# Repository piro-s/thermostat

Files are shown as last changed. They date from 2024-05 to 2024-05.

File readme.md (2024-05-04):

# Thermostat:  
A board for connecting an inductive load (the width of the tracks allows you  
to connect up to 5A); if large currents are required, then a connector is  
provided for connecting control signals of an external relay (Relay Control).  
Scheme was made using the [article](https://habr.com/ru/companies/unwds/articles/390601/).  

### Schemes:  
###### thermostat_v0.1:  
[pdf](docs/thermostat_v0.1.pdf)  

### Images:  
###### thermostat_v0.1:  
top:  
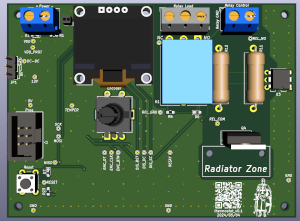
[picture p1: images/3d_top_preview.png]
thermostat_v0.1_top
  
bottom:  
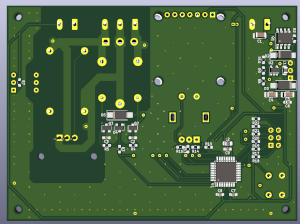
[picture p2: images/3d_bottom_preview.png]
thermostat_v0.1_bottom
  
assembly:  
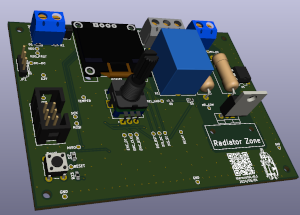
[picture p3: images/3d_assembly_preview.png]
thermostat_v0.1_ass
  

###### gerber:  
Archive for production:  
[thermostat_v0.1](https://github.com/piro-s/thermostat/raw/main/gerber/thermostat_v0.1.zip)

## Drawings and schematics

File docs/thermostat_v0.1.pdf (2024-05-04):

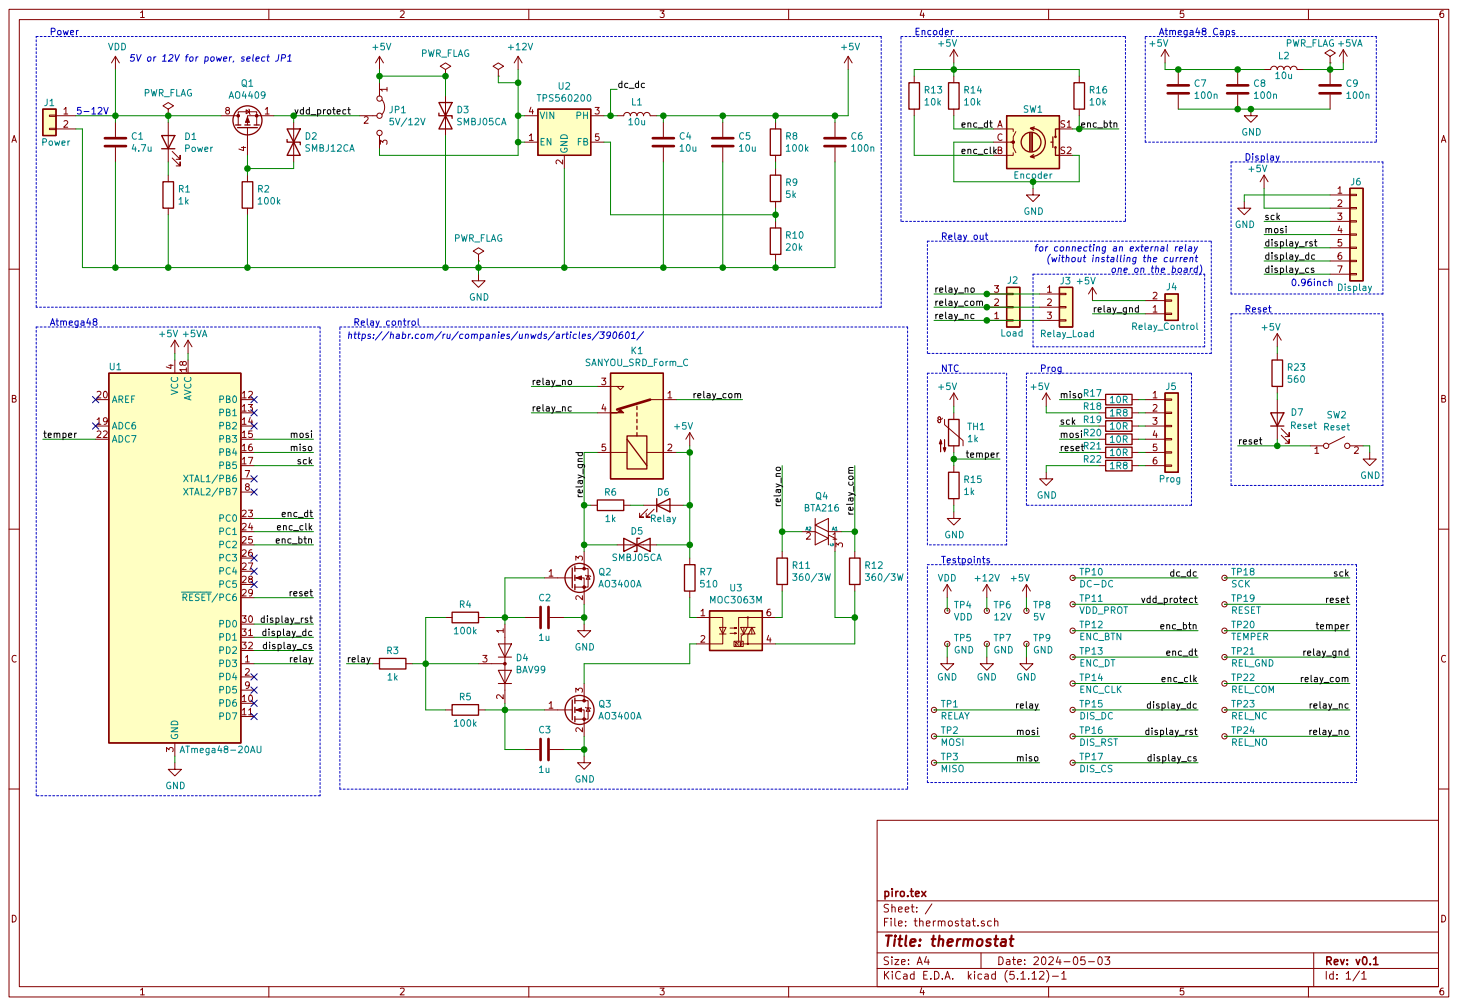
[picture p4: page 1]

5V or 12V for power, select JP1

for connecting an external relay
(without installing the current

one on the board)

Id: 1/1 Title: thermostat File: thermostat.sch Sheet: / piro.tex

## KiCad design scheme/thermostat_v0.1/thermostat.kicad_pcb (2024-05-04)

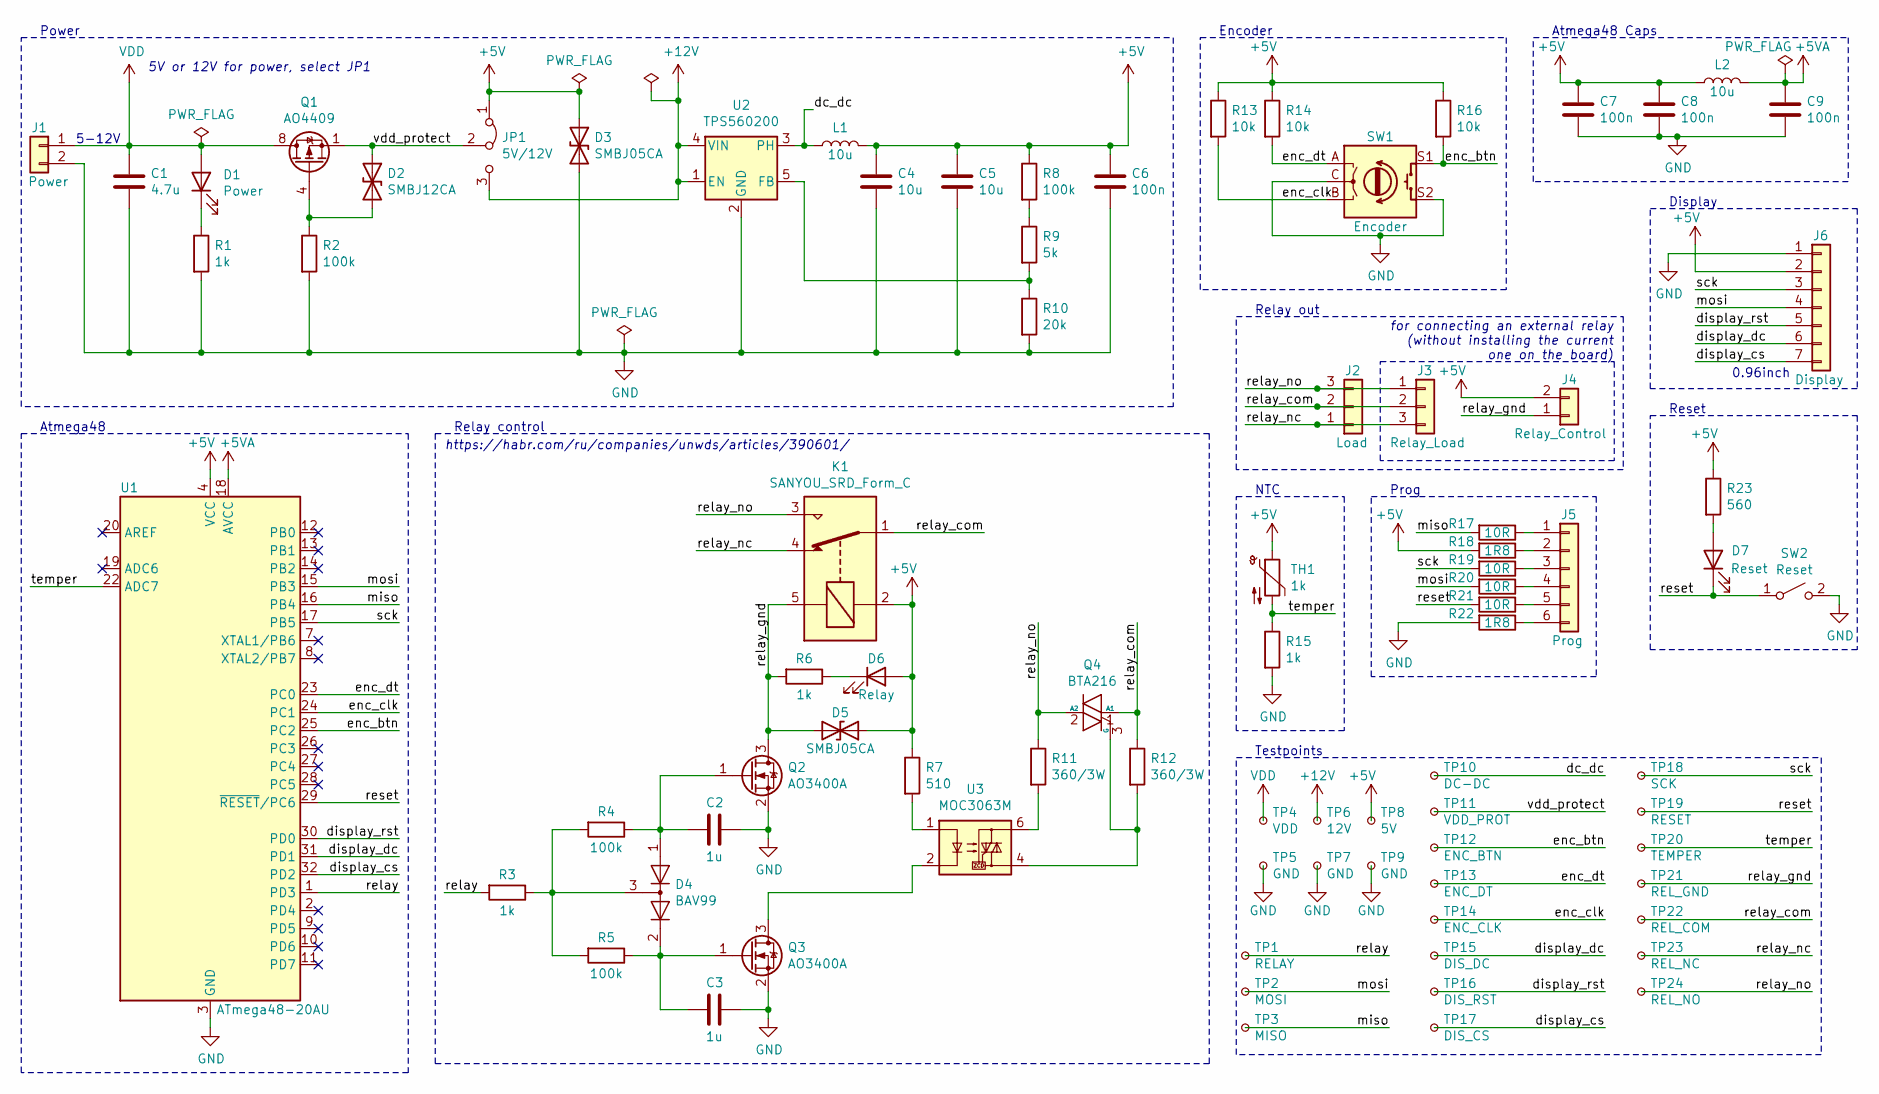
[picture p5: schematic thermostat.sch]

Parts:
C1: 4.7u; C_1206_3216Metric_Pad1.33x1.80mm_HandSolder
C2, C3: 1u; C_0603_1608Metric_Pad1.08x0.95mm_HandSolder
C4, C5: 10u; C_1206_3216Metric_Pad1.33x1.80mm_HandSolder
C6, C7, C8, C9: 100n; C_0603_1608Metric_Pad1.08x0.95mm_HandSolder
D1: Power; D_0603_1608Metric_Pad1.05x0.95mm_HandSolder
D2: SMBJ12CA; D_SMA_Handsoldering
D3, D5: SMBJ05CA; D_SMA_Handsoldering
D4: BAV99; SOT-23
D6: Relay; D_0603_1608Metric_Pad1.05x0.95mm_HandSolder
D7: Reset; D_0603_1608Metric_Pad1.05x0.95mm_HandSolder
J1: Power; PhoenixContact_MCV_1,5_2-G-5.08_1x02_P5.08mm_Vertical
J2: Load; PhoenixContact_MCV_1,5_3-G-5.08_1x03_P5.08mm_Vertical
J3: Relay_Load; SolderWire-0.75sqmm_1x03_P4.8mm_D1.25mm_OD2.3mm
J4: Relay_Control; PhoenixContact_MCV_1,5_2-G-5.08_1x02_P5.08mm_Vertical
J5: Prog; IDC-Header_2x03_P2.54mm_Vertical
J6: Display; Display_WAVGAT_0.96
JP1: 5V/12V; PinHeader_1x03_P2.54mm_Vertical
K1: SANYOU_SRD_Form_C; Relay_SPDT_SANYOU_SRD_Series_Form_C
L1, L2: 10u; L_0805_2012Metric_Pad1.15x1.40mm_HandSolder
Q1: AO4409; SOIC-8_3.9x4.9mm_P1.27mm
Q2, Q3: AO3400A; SOT-23
Q4: BTA216; TO-220-3_Vertical
R1, R3, R6, R15: 1k; R_0603_1608Metric_Pad0.98x0.95mm_HandSolder
R2, R4, R5, R8: 100k; R_0603_1608Metric_Pad0.98x0.95mm_HandSolder
R7: 510; R_0603_1608Metric_Pad0.98x0.95mm_HandSolder
R9: 5k; R_0603_1608Metric_Pad0.98x0.95mm_HandSolder
R10: 20k; R_0603_1608Metric_Pad0.98x0.95mm_HandSolder
R11, R12: 360/3W; R_Axial_DIN0617_L17.0mm_D6.0mm_P20.32mm_Horizontal
R13, R14, R16: 10k; R_0603_1608Metric_Pad0.98x0.95mm_HandSolder
R17, R19, R20, R21: 10R; R_0603_1608Metric_Pad0.98x0.95mm_HandSolder
R18, R22: 1R8; R_0603_1608Metric_Pad0.98x0.95mm_HandSolder
R23: 560; R_0603_1608Metric_Pad0.98x0.95mm_HandSolder
SW1: Encoder; RotaryEncoder_Alps_EC11E-Switch_Vertical_H20mm
SW2: Reset; SW_PUSH_6mm
TH1: 1k; PinSocket_1x02_P1.27mm_Vertical
TP1: RELAY; TestPoint_THTPad_D1.0mm_Drill0.5mm
TP2: MOSI; TestPoint_THTPad_D1.0mm_Drill0.5mm
TP3: MISO; TestPoint_THTPad_D1.0mm_Drill0.5mm
TP4: VDD; TestPoint_THTPad_D1.0mm_Drill0.5mm
TP5, TP7, TP9: GND; TestPoint_THTPad_D1.0mm_Drill0.5mm
TP6: 12V; TestPoint_THTPad_D1.0mm_Drill0.5mm
TP8: 5V; TestPoint_THTPad_D1.0mm_Drill0.5mm
TP10: DC-DC; TestPoint_THTPad_D1.0mm_Drill0.5mm
TP11: VDD_PROT; TestPoint_THTPad_D1.0mm_Drill0.5mm
TP12: ENC_BTN; TestPoint_THTPad_D1.0mm_Drill0.5mm
TP13: ENC_DT; TestPoint_THTPad_D1.0mm_Drill0.5mm
TP14: ENC_CLK; TestPoint_THTPad_D1.0mm_Drill0.5mm
TP15: DIS_DC; TestPoint_THTPad_D1.0mm_Drill0.5mm
TP16: DIS_RST; TestPoint_THTPad_D1.0mm_Drill0.5mm
TP17: DIS_CS; TestPoint_THTPad_D1.0mm_Drill0.5mm
TP18: SCK; TestPoint_THTPad_D1.0mm_Drill0.5mm
TP19: RESET; TestPoint_THTPad_D1.0mm_Drill0.5mm
TP20: TEMPER; TestPoint_THTPad_D1.0mm_Drill0.5mm
TP21: REL_GND; TestPoint_THTPad_D1.0mm_Drill0.5mm
TP22: REL_COM; TestPoint_THTPad_D1.0mm_Drill0.5mm
TP23: REL_NC; TestPoint_THTPad_D1.0mm_Drill0.5mm
TP24: REL_NO; TestPoint_THTPad_D1.0mm_Drill0.5mm
U1: ATmega48-20AU; TQFP-32_7x7mm_P0.8mm
U2: TPS560200; SOT-23-5
U3: MOC3063M; DIP-6_W7.62mm

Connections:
+5V: C4.1, C5.1, C6.1, C7.1, C8.1, D3.1 (A1), D5.1 (A1), D6.2 (A), J4.2, J6.2, JP1.1 (A), K1.2, L1.2, L2.1, R7.1, R8.1, R13.1, R14.1, R16.1, R18.2, R23.1, TH1.1, TP8.1, U1.4 (VCC), U1.6 (VCC)
+5VA: C9.1, L2.2, U1.18 (AVCC)
+12V: JP1.3 (B), TP6.1, U2.1 (EN), U2.4 (VIN)
/dc_dc: L1.1, TP10.1, U2.3 (PH)
/display_cs: J6.7, TP17.1, U1.32 (PD2)
/display_dc: J6.6, TP15.1, U1.31 (PD1)
/display_rst: J6.5, TP16.1, U1.30 (PD0)
/enc_btn: R16.2, SW1.S1, TP12.1, U1.25 (PC2)
/enc_clk: R13.2, SW1.B, TP14.1, U1.24 (PC1)
/enc_dt: R14.2, SW1.A, TP13.1, U1.23 (PC0)
/miso: R17.2, TP3.1, U1.16 (PB4)
/mosi: J6.4, R20.2, TP2.1, U1.15 (PB3)
/relay: R3.2, TP1.1, U1.1 (PD3)
/relay_com: J2.2, J3.2, K1.1, Q4.1 (A1), R12.1, TP22.1
/relay_gnd: D5.2 (A2), J4.1, K1.5, Q2.3 (D), R6.2, TP21.1
/relay_nc: J2.1, J3.3, K1.4, TP23.1
/relay_no: J2.3, J3.1, K1.3, Q4.2 (A2), R11.1, TP24.1
/reset: D7.1 (K), R21.2, SW2.1 (A), TP19.1, U1.29 (~RESET~/PC6)
/sck: J6.3, R19.2, TP18.1, U1.17 (PB5)
/temper: R15.1, TH1.2, TP20.1, U1.22 (ADC7)
/vdd_protect: D2.1 (A1), JP1.2 (C), Q1.1 (S), Q1.2 (S), Q1.3 (S), TP11.1
GND: C1.2, C2.1, C3.1, C4.2, C5.2, C6.2, C7.2, C8.2, C9.2, D3.2 (A2), J1.2, J6.1, Q2.2 (S), Q3.2 (S), R1.2, R2.2, R10.2, R15.2, R22.2, SW1.C, SW1.S2, SW2.2 (B), TP5.1, TP7.1, TP9.1, U1.3 (GND), U1.5 (GND), U1.21 (GND), U2.2 (GND)
unnamed: C2.2, D4.1 (K), Q2.1 (G), R4.1
unnamed: C3.2, D4.2 (A), Q3.1 (G), R5.1
unnamed: D1.1 (K), R1.1
unnamed: D2.2 (A2), Q1.4 (G), R2.1
unnamed: D4.3 (K), R3.1, R4.2, R5.2
unnamed: D6.1 (K), R6.1
unnamed: D7.2 (A), R23.2
unnamed: J5.1, R17.1
unnamed: J5.2, R18.1
unnamed: J5.3, R19.1
unnamed: J5.4, R20.1
unnamed: J5.5, R21.1
unnamed: J5.6, R22.1
unnamed: Q3.3 (D), U3.2
unnamed: Q4.3 (G), R12.2, U3.4
unnamed: R7.2, U3.1
unnamed: R8.2, R9.1
unnamed: R9.2, R10.1, U2.5 (FB)
unnamed: R11.2, U3.6
VDD: C1.1, D1.2 (A), J1.1, Q1.5 (D), Q1.6 (D), Q1.7 (D), Q1.8 (D), TP4.1

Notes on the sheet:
Power
Atmega48 Caps
NTC
Encoder
for connecting an external relay (without installing the current one on the board)
Relay out
Relay control
https://habr.com/ru/companies/unwds/articles/390601/
5-12V
Reset
Prog
0.96inch
Display
Atmega48
Testpoints
5V or 12V for power, select JP1

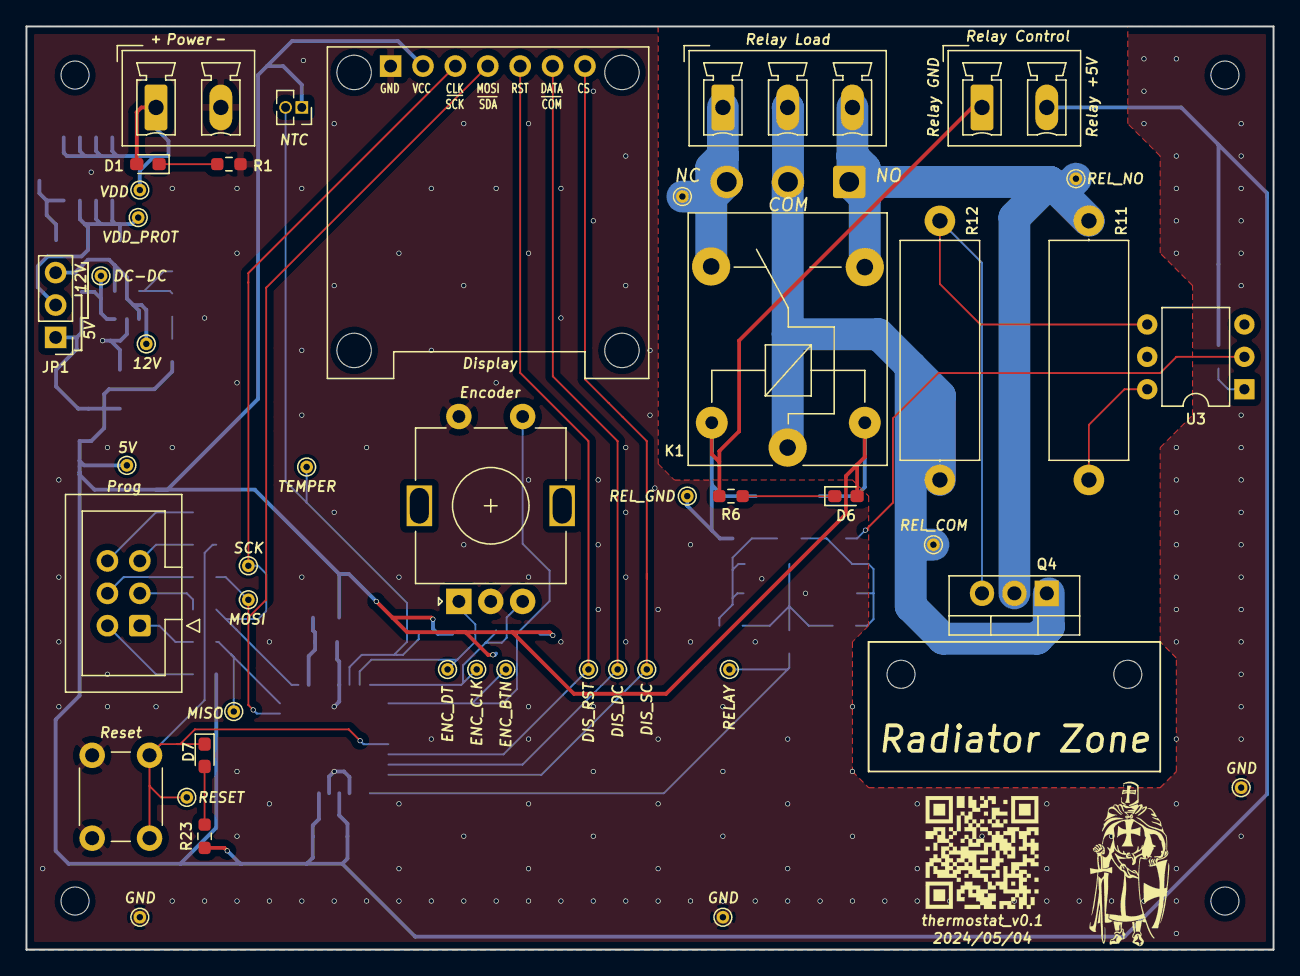
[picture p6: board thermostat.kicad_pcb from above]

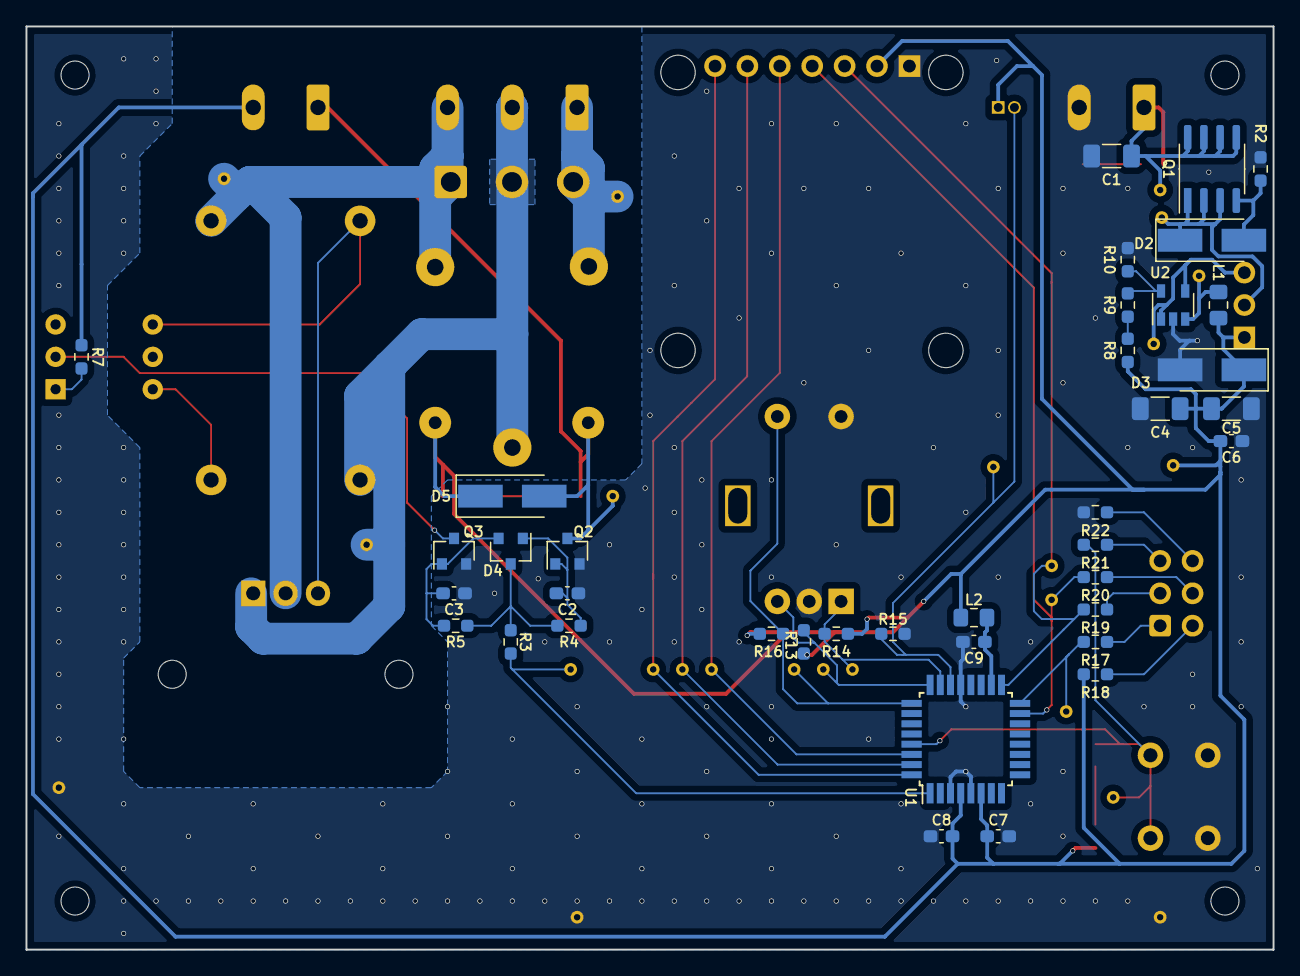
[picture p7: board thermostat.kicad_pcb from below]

Board: 2 copper layers, 97.8 x 72.4 mm, 83 parts (38 on the bottom side), 42 nets.
